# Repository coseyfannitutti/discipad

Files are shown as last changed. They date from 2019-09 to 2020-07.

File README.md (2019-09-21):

# discipad
 17-key numpad assembled with only through hole components, including usb type-c

[BOM, Build Guide, and Flashing Information](./doc)

Kits available at [cftkb.com](https://www.cftkb.com)

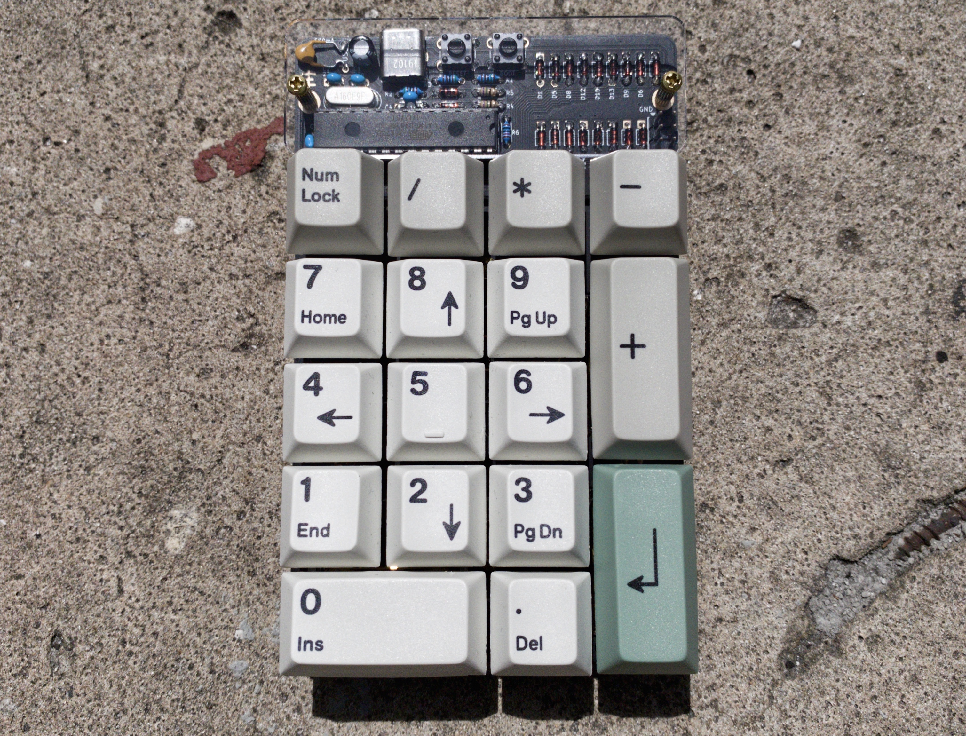
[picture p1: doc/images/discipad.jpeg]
discipad

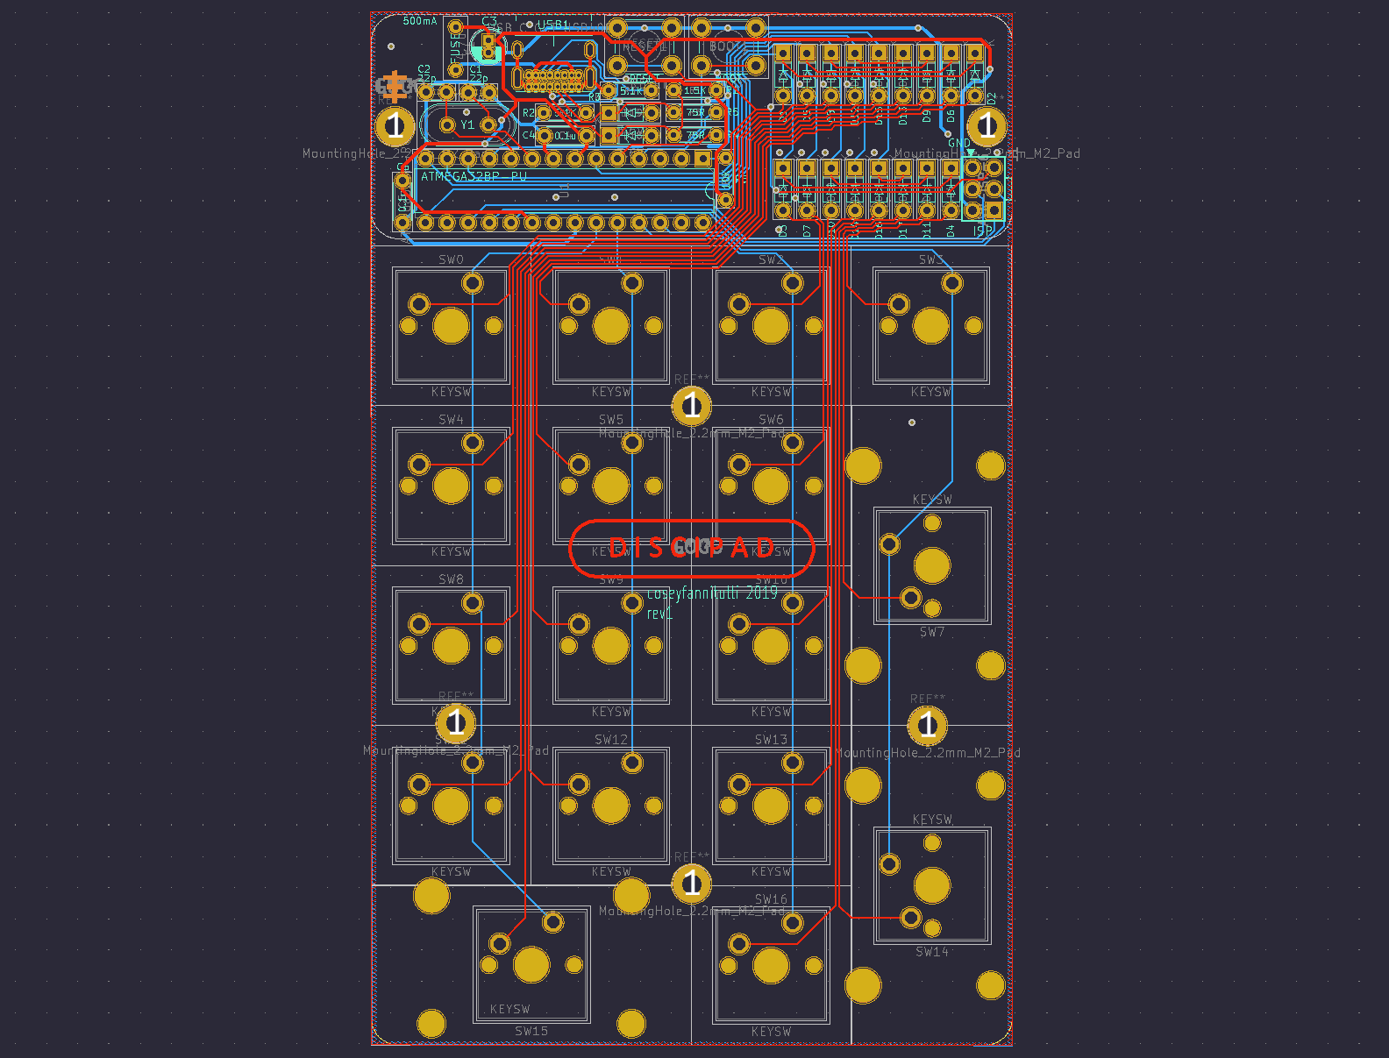
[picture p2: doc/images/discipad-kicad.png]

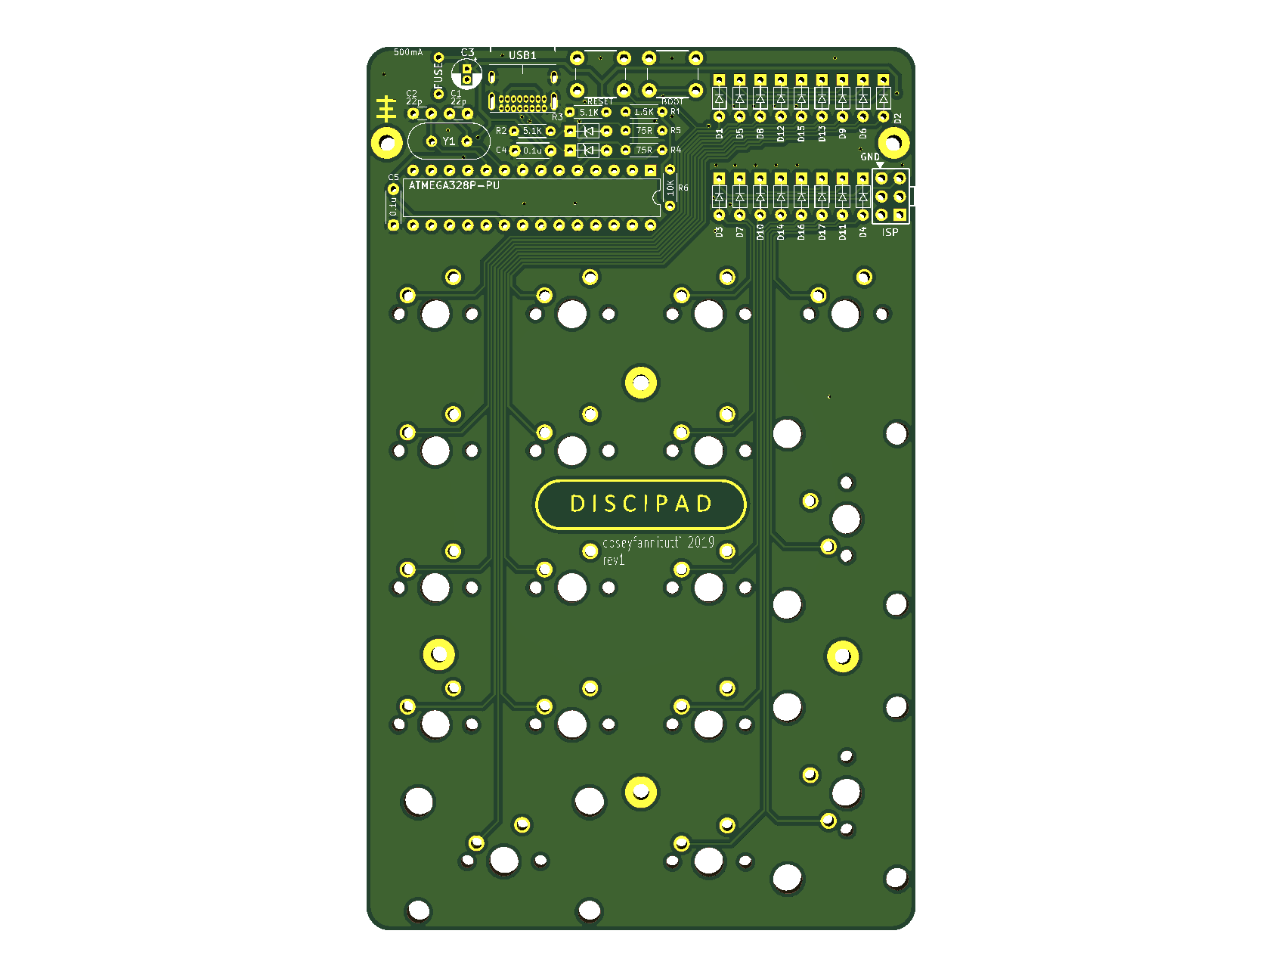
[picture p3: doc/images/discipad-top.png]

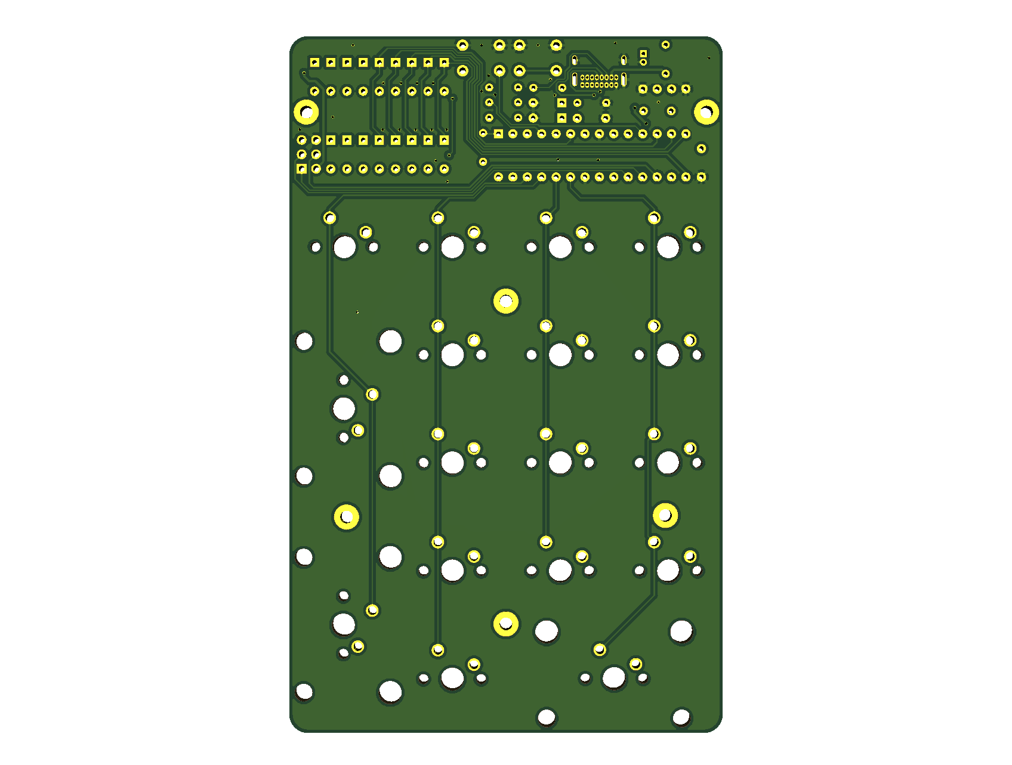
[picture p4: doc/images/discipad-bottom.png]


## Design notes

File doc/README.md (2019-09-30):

# DISCIPAD

[Build Guide](https://static1.squarespace.com/static/5c533d33348cd92b886e544d/t/5d90e24fbd027f6ecf7cfb2a/1569776210721/DISCIPAD+BUILD+GUIDE.pdf)

[QMK Toolbox Flashing Guide (Recommended)](https://static1.squarespace.com/static/5c533d33348cd92b886e544d/t/5d8ee3dc9135ee1aa9e99cd6/1569645533886/DISCIPAD+FLASHING+GUIDE.pdf)

[Command Line Flashing Guide (Advanced)](https://static1.squarespace.com/static/5c533d33348cd92b886e544d/t/5d8ee3c1f21a152c431c6f4b/1569645506482/DISCIPAD+FLASHING+GUIDE+-+COMMAND+LINE.pdf)

[Bootloader](./bootloader)

[BOM (Parts List)](https://octopart.com/bom-tool/zkOB9ZlB)

discipad

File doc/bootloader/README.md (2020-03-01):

# Bootloader

## If you buy a kit from cftkb.com your microcontroller already has the bootloader flashed and you do not need this.

This project uses USBaspLoader as the usb bootloader on the atmega328p.
- My custom bootloader:   
https://github.com/coseyfannitutti/USBaspLoader/tree/atmega328p
  - Please ensure you are in the atmega328p branch of my fork of the USBaspLoader repository when downloading.
  - Follow the directions in the readme for directions on setting up the build environment for your operating system as well as flash instructions.
  - Makefile.inc sets flashing device as usbtiny, as I use a sparkfun pocket avr programmer. If you need to use another programmer please edit line 41 of Makefile.inc accordingly. Only edit Makefile.inc, and NEVER directly edit the actual Makefile.
  - Commands for flashing once build environment is set up:
  
	```make flash``` (flashes makefile)
  
  	```make fuse``` (sets fuses for microcontroller)
  
## Enter bootloader mode
1. Press and hold ```BOOT``` switch
2. Tap ```RESET``` switch
3. Release ```BOOT``` switch

Alternatively, you can hold ```BOOT``` switch while inserting the USB cable.

If you have successfully entered bootloader mode you should see USBaspLoader in device manager or as a connected device in QMK Toolbox.

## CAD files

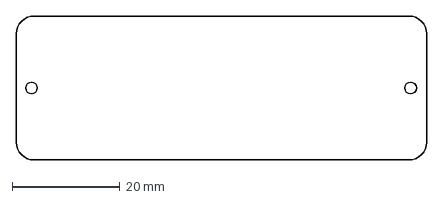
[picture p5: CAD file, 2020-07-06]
discipad-acrylic-guard.dxf
76.3 x 26.7 mm

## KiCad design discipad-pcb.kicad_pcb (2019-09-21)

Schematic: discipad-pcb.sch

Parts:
BOOT1: BOOT
C1, C2: 22p; C_Disc_D3.0mm_W1.6mm_P2.50mm
C3: 4.7u; CP_Radial_D4.0mm_P1.50mm
C4, C5: 0.1u; C_Disc_D4.3mm_W1.9mm_P5.00mm
D1, D2, D3, D4, D5, D6, D7, D8, D9, D10, D11, D12, D13, D14, D15, D16, D17: D_DO-35_SOD27_P5.08mm_Horizontal
D18, D19: 3.6V; D_DO-35_SOD27_P5.08mm_Horizontal
F1: 100mA; polyfuse_5.1mm
J1: AVR-ISP-6
LED1: POWER
R1: 1.5K; R_Axial_DIN0204_L3.6mm_D1.6mm_P5.08mm_Horizontal
R2, R3: 5.1K; R_Axial_DIN0204_L3.6mm_D1.6mm_P5.08mm_Horizontal
R4, R5: 75R; R_Axial_DIN0204_L3.6mm_D1.6mm_P5.08mm_Horizontal
R6: 10K; R_Axial_DIN0204_L3.6mm_D1.6mm_P5.08mm_Horizontal
R7: 1.5K
RESET1: RESET; SW_PUSH_6mm
SW0, SW1, SW2, SW3, SW4, SW5, SW6, SW8, SW9, SW10, SW11, SW12, SW13, SW16: KEYSW; SW_Cherry_MX1A_1.00u_PCB-NOSCREEN
SW7, SW14: KEYSW; SW_Cherry_MX1A_2.00u_Vertical_PCB
SW15: KEYSW; SW_Cherry_MX1A_2.00u_PCB_FLIPPED
U1: ATmega328P-PU; DIP-28_W7.62mm
USB1: USB_C_GCT_USB4085
Y1: Crystal; Crystal_HC49-4H_Vertical

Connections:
+5V: C3.1, C4.1, C5.1, F1.1, J1.2, R1.1, R6.1, U1.7 (VCC), U1.20 (AVCC)
D+: R5.1, U1.4 (PD2)
D-: R4.2, U1.5 (PD3)
GND: BOOT1.1, C1.2, C2.2, C3.2, C4.2, C5.2, D18.2, D19.2, J1.6, R2.1, R3.1, RESET1.1, U1.8 (GND), U1.22 (GND), USB1.A1, USB1.A12, USB1.B1, USB1.B12, USB1.S1
unnamed: D1.2, SW0.2
unnamed: D2.2, SW1.2
unnamed: D3.2, SW2.2
unnamed: D4.2, SW3.2
unnamed: D5.2, SW4.2
unnamed: D6.2, SW5.2
unnamed: D7.2, SW6.2
unnamed: D8.2, SW8.2
unnamed: D9.2, SW9.2
unnamed: D10.2, SW10.2
unnamed: D11.2, SW7.2
unnamed: D12.2, SW11.2
unnamed: D13.2, SW12.2
unnamed: D14.2, SW13.2
unnamed: D15.2, SW15.2
unnamed: D16.2, SW16.2
unnamed: D17.2, SW14.2
unnamed: D18.1, R1.2, R4.1, USB1.A7, USB1.B7
unnamed: D19.1, R5.2, USB1.A6, USB1.B6
unnamed: R2.2, USB1.A5
unnamed: R3.2, USB1.B5
VCC: F1.2, USB1.A4, USB1.A9, USB1.B4, USB1.B9
boot: BOOT1.2, U1.11 (PD5)
col0: SW0.1, SW4.1, SW8.1, SW11.1, SW15.1, U1.23 (PC0)
col1: SW1.1, SW5.1, SW9.1, SW12.1, U1.24 (PC1)
col2: SW2.1, SW6.1, SW10.1, SW13.1, SW16.1, U1.25 (PC2)
col3: SW3.1, SW7.1, SW14.1, U1.26 (PC3)
miso: J1.1, U1.18 (PB4)
mosi: J1.4, U1.17 (PB3)
reset: J1.5, R6.2, RESET1.2, U1.1 (~RESET~/PC6)
row0: D1.1, D2.1, D3.1, D4.1, U1.15 (PB1)
row1: D5.1, D6.1, D7.1, U1.14 (PB0)
row2: D8.1, D9.1, D10.1, D11.1, U1.13 (PD7)
row3: D12.1, D13.1, D14.1, U1.12 (PD6)
row4: D15.1, D16.1, D17.1, U1.6 (PD4)
sck: J1.3, U1.19 (PB5)
xtal1: C1.1, U1.9 (XTAL1/PB6), Y1.1
xtal2: C2.1, U1.10 (XTAL2/PB7), Y1.2

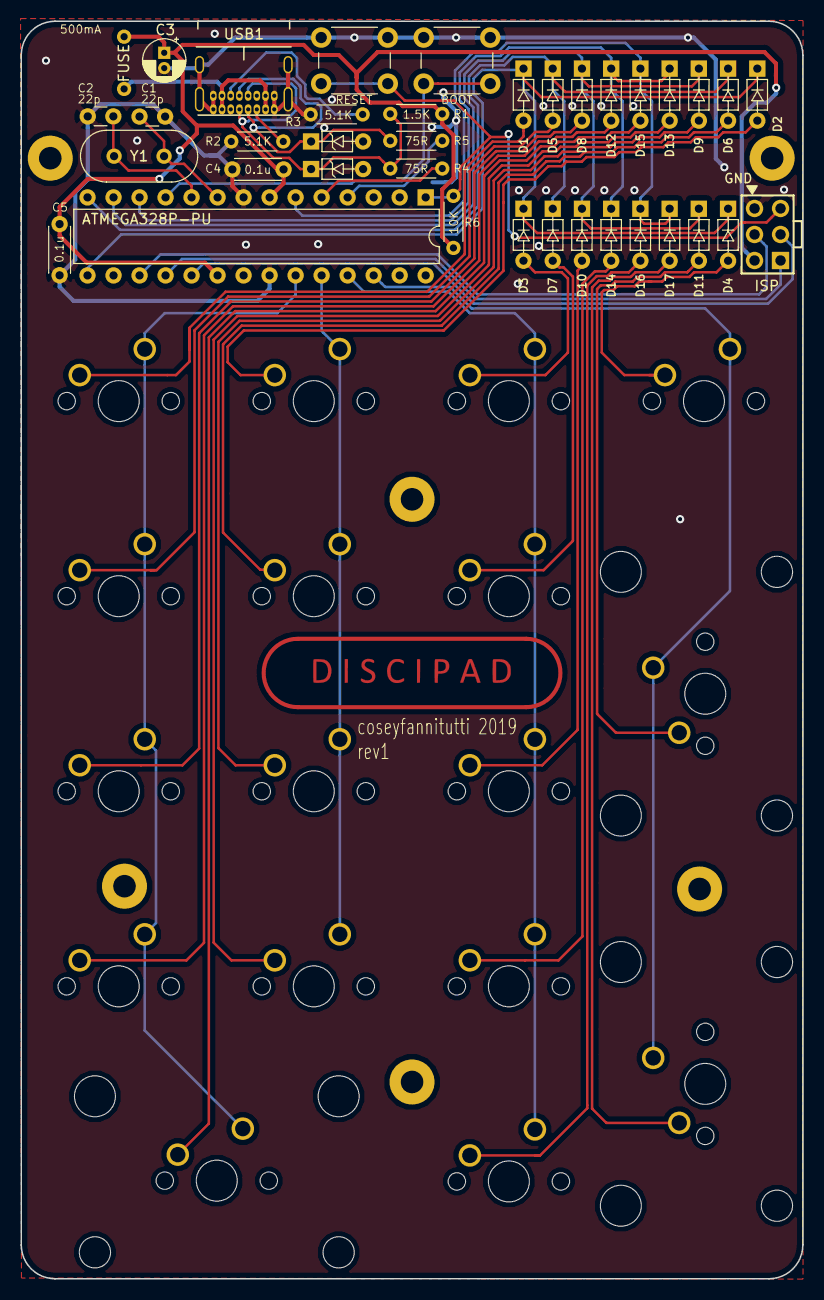
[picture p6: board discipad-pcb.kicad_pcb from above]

Board: 2 copper layers, 76.3 x 122.8 mm, 54 parts (0 on the bottom side), 42 nets.

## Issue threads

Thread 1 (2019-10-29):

USB-C Connector GCT USB4085 not available anywhere

LouWii, 2019-10-29:
Hi there

Thanks for open sourcing the discipad! I needed to order a few custom PCBs and thought "why not put some Discipad" with them, as a fun side-project.

The problem is, I haven't checked the components availability, thinking this wouldn't be an issue. Well, it turns out one of the most important component is gone, the USB C socket used isn't available anywhere. Does someone know of a drop-in replacement somewhere? Or should we work on replacing it with something else?

I'm afraid my PCB order is f*ed though, the only thing I can do is manually re-wire it to another USB C socket. or maybe try and change it to a standard mini or micro USB.

coseyfannitutti, 2019-11-02:
Yes, as far as I can see all distributors that I am aware of have them backordered. However, they are all saying they will have more stock within a few weeks. The part is not discontinued, so I don't have any plans to change it on my end at this time.

LouWii, 2019-11-02:
Ah ok, that's good to know. I'm going to contact my sources and see if they
will eventually get some. Thanks for letting me know

Le sam. 2 nov. 2019 à 08:02, coseyfannitutti <notifications@github.com> a
écrit :

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

Closed 2019-11-02.

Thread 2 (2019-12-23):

USB4085 Not easy to buy and expensive

TZKJ2008, 2019-12-23:
I have contacted many suppliers, they said that this specification is rarely made and sold, it is a special model, I hope you can change to a more commonly used model, thank you!

coseyfannitutti, 2019-12-23:
Digikey currently has nearly 8000 available for about $1 and export.farnell.com in Europe also stocks them regularly.

Because it is in fact available I would rather not change it, but it is licensed to allow you to change the footprint and produce the board yourself if shipping usb4085-gf-a port is expensive to your country.

Closed 2019-12-23.

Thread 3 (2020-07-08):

Power led in the schematic, but not on the pcb.

BenRoe, 2020-07-08:
Hi,
thank you for the beautiful numpad.
I noticed that the power led (LED1) and the related resistor 1.5K (R7) are in the schematic, but not on the pcb.
I guess you did not placed it, because of the lack of space, or was there some other reason?

If we finde a fuse which does not need to bend down, then there is some space in the top left corner.

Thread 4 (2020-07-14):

Dicipad Dimensions

bryanicallaghan, 2020-07-14:
Looking through the Dicipad files and am having some trouble finding the pcb dimensions.

I tried to measure via Kicad and I'm coming up with a width of 76.61mm X 122.85mm and 1.6mm thickness

Should I round up to 77mm X 123mm or down to 76mm X 122mm? or am I way off altogether?

TIA!

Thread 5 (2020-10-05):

Acrylic file cant be open on AutoCAD

SaltedPeanut, 2020-10-05:
Hey Im having this issue that your DXF file for The acrylic piece can't be open using AutoCAD

nick-1666, 2021-11-11:
use kicad.

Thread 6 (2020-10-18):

While testing keys, shorting one switch activates 4 and 7.

untendedcampfire, 2020-10-18:
Like the title says, I was testing my new Discipad after soldering everything together. When I got to the 7 and 4 switches they would activate both when I would short only one. For example, I will short the "4" holes and it will activate 4 and 7. Same for the "7" holes it would activate 4 and 7. My limited knowledge on electronics and pcb's is telling me there is a short on the diodes or the ATMEGA chip is seated incorrectly. Please let me know what troubleshooting steps I can take.

Thank you in advanced.

untendedcampfire, 2020-10-22:
Thanks to the great discord community I was able to resolve the issue. My problem occurred due to the USB-C port not being soldered on properly. The solution was to remove all the solder then reapply while also adding more solder to ensure the pins were well attached to the pad.

Closed 2020-10-22.

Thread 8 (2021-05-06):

Pdf Screws error

SuperNici, 2021-05-06:
In the PDF the number is missing to the left of the mm on the first screw.
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

SuperNici, 2021-05-06:
It should say "12x M2 4mm screws"

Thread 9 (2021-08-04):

Hot swap variant

BlkPingu, 2021-08-04:
Any chance we could get a hot swap variant with base plate and case files for CNC and/or laser cutting?
